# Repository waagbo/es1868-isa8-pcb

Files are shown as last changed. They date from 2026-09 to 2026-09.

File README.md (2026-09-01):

# ES1868F 8bit ISA Sound Card

## Introduction

This is a sound card for the ISA 8bit bus sporting the **ES1868F** chip by *ESS Technology*.

This chip provides **Sound Blaster PRO 2.0** (stereo), **OPL3** compatibility (via *ESFM*), MPU-401 support and is considered one of the [best chips](https://www.philscomputerlab.com/ess-audiodrive-es1868.html) used in clone cards.

Rev. 1.1 Board

This board provides the following connections:

* Speaker out (amplified)
* Line out
* Line in
* AUX in (internal header, since rev 1.2)
* Microphone in (internal header)
* Joystick port
* MIDI on Joystick port
* Wavetable header
* Volume control header

### Disclaimer

I take NO responsibility for what happens if you decide to build and use this card. Your computer might crash, catch fire or be destroyed in other nasty ways.
You're encourauged to take what you deem fit from this, and use it in your projects!

### Functionalities

✅ means I tested the functionality and it works, ❌ means I tested the functionality and found issues, ? means that the functionality has yet to be tested.

* [✅] FM Synthesis via OPL3 clone (**ESFM**)
* [✅] Digital audio playback
* [✅] Stereo (left/right channel) check (Tested with Sound Blaster PRO Test program, digitized sound mode)
* [✅] Joystick port
* [✅] Speaker Out (amplified)
* [✅] Line out
* [✅] Line in
* [✅] AUX In
* [?] Microphone in
* [✅] MIDI output via Joystick port (tested using DOSMID MPU mode on a Roland SC55)
* [✅] Wavetable daughterboard

The card was tested on:

* [✅] 286 16Mhz / DOS 6.22
* [✅] NEC V20 9.54Mhz / DOS 6.22 (Use **UNISOUND**, see **Configuration** section below)
* [✅] NEC V20 4.77Mhz / DOS 6.22 (Use **UNISOUND**, see **Configuration** section below)
* [✅] 8088 8Mhz / DOS 6.22 (Use **UNISOUND**, see **Configuration** section below)
* [✅] 8088 4.77Mhz / DOS 6.22 (Use **UNISOUND**, see **Configuration** section below)
* [✅] 486DX 40Mhz / DOS 7.1 (Use **UNISOUND**, see **Configuration** section below)
* [✅] Am5x86 40/160Mhz / DOS 7.1 (Use **UNISOUND**, see **Configuration** section below)

## Configuration

This card is jumperless and must be configured before use.
Under DOS you can us the [ESSCFG](software/ESSCFG.EXE) tool and tweak the volume via [ESSVOL](software/ESSVOL.EXE).

The **recommended** way to do this (especially under a very slow machine, like a V20/8088) is by using the [UNISOUND](https://www.vogons.org/viewtopic.php?f=62&t=72553) configurator.

It's important to add the `/XEA` parameter to `UNISOUND.COM` when using it, and remember to execute it after setting the `BLASTER` environment variable, for example with the command `SET BLASTER=A220 I5 D1 P330 T5 J201` (clearly changing the parameters depending on your setup).

**WARNING**: If you use an XT-IDE adapter at the default base address (300h), remember to set the MPU-401 base for this card to something else (like 330h)!

## Bill of Materials

See [BOM_smd.md](BOM_smd.md) / [BOM_smd.csv](BOM_smd.csv) for the SMD variant of the board
(`ISA_ES1868_smd.*`, see [SMD_CONVERSION.md](SMD_CONVERSION.md)), with DigiKey, Mouser and
LCSC part numbers.

Value of L1/L2/L3 ferrite beads is non critical. On the original THT board I used [these](https://www.mouser.it/ProductDetail/623-2743001112LF); the SMD variant uses the same 0805 bead as L4–L9/L12.

## Known Issues

### Rev 1.0

* Joystick plug "J3" silkscreen overlaps with some resistors (fixed in 1.1).
* The thread in the audio jacks I'm using (Kycon STX-3100-3CB) is flush with the bracket, so if the bracket has some bending, the plug risks to be pushed away (fixed in 1.1 by moving the connectors 0,5mm towards the edge).

## Credits

Thanks to [Sergey Kiselev](https://github.com/skiselev) for his symbol/footprint library!

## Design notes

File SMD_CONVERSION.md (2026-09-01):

# SMD Conversion Notes (`ISA_ES1868_smd`)

`ISA_ES1868_smd.kicad_pcb` / `.kicad_sch` / `.kicad_pro` are a copy of the rev 1.2 project
with through-hole parts converted to hand-solderable SMD footprints. The files are saved in
KiCad 10 format (the original rev 1.2 files are untouched and remain KiCad 7).

## What was converted

| Group | Old footprint | New footprint | Refs |
|---|---|---|---|
| Ceramic disc capacitors (38) | `C_Disc_D6.0mm` / `D3.8mm` | `C_0805_..._HandSolder` | C1–C11, C15–C33, C38–C41, C46–C48, C53 |
| 10 µF electrolytics on supply/bias nets (5) | `CP_Radial_D5.0mm` | `C_0805_..._HandSolder` (MLCC) | C12, C13, C50, C51, C52 |
| Resistors (34) | `R_Axial_DIN0207` | `R_0805_..._HandSolder` | R1–R18, R22–R37 |
| Axial ferrite beads (3) | `L_Axial_Vishay_IM-1` | `L_0805_..._HandSolder` | L1, L2, L3 (now same bead as L4–L9/L12) |
| 78L05 regulator | TO-92 | `SOT-89-3_Handsoldering` | U1 (pin functions 1=OUT/2=GND/3=IN identical in both packages) |
| 74LS138 decoder | DIP-16 | `SOIC-16_3.9x9.9mm` | U2 |
| 93LC66 EEPROM | DIP-8 | `SOIC-8_3.9x4.9mm` | U4 |

All converted parts keep their original position, rotation, reference, value and pad-net
assignments (verified pad-by-pad against the original board — zero net differences).

Like the original board, the converted parts print their **value on the front silkscreen**
(1×1 mm text, 0.15 mm stroke — same style as the THT originals). Ferrite beads keep their
values hidden, matching the original convention for L4–L12. Expect to nudge some value labels
apart while re-routing dense areas.

## What deliberately stays through-hole

* **U3 ES1868F** — already SMD (LQFP).
* **U7 LM1877 (DIP-14)** — no SMD package of this part ever existed; the chip itself is obsolete
  (see BOM notes).
* **Audio-path electrolytics** — kept as THT radial on purpose:
  * C36, C37 (10 µF): line-out coupling caps. A ceramic here would add DC-bias/piezo distortion;
    a leaded electrolytic (or audio-grade type) is the better part, and THT radials are trivial
    to hand solder.
  * C34, C35 (470 µF): speaker output coupling after the LM1877.
  * C14, C43 (47 µF): ES1868 VREF/CMR filter and LM1877 bias bypass — value too large for a
    sane 0805 ceramic, and both sit in audio-relevant reference nodes.
  * C42 (100 µF): amplifier supply bulk on `/Filtered_12V`.
* **Y1 crystal, all connectors, ISA edge, solder jumpers** — unchanged.

## Audio-circuit classification of the capacitors

Positions that are **in the audio signal path** (choose good dielectrics here):

| Refs | Function | Recommendation |
|---|---|---|
| C27, C28 (220 nF) | Line-in coupling | 50 V X7R 0805 (voltage headroom minimises C(V) distortion) |
| C31, C32 (220 nF) | AUX A coupling | 50 V X7R 0805 |
| C29, C30 (220 nF) | AUX B (wavetable) coupling | 50 V X7R 0805 |
| C8, C9 (220 nF) | FM out → codec in coupling | 50 V X7R 0805 |
| C47, C48 (220 nF) | LM1877 input coupling | 50 V X7R 0805 |
| C6 (100 nF) | Mic coupling | 50 V X7R 0805 |
| C10, C33 (1 nF) | Codec input filters | **C0G/NP0** |
| C38, C39 (10 nF) | LM1877 feedback | **C0G/NP0** |
| C40, C41 (100 nF) | LM1877 Zobel/snubber | 50 V X7R |
| C36, C37 (10 µF) | Line-out coupling | THT electrolytic (audio grade optional) |
| C34, C35 (470 µF) | Speaker coupling | THT electrolytic |

The original card used ceramic discs in all the small-value audio positions, so 0805 MLCCs are
not a downgrade — using 50 V-rated X7R (never Y5V/X5R for coupling) keeps distortion negligible
at ~1 Vrms line levels.

Non-audio positions: supply decoupling (C1–C5, C17, C50–C53, C12, C42), joystick timing caps
(C18–C21, C23–C26 — use **C0G** so gameport position readings stay stable with temperature),
crystal load caps (C15, C16 — **C0G**), reset filter (C46), VREF/bias filters (C7, C11, C13, C14,
C22, C43).

## Layout status — re-routing required

The converted footprints sit at the old component centroids, but 0805 pads do not land on the
old THT pad locations, so **the tracks around every converted part need to be re-routed** before
fabrication. DRC (`kicad-cli pcb drc --schematic-parity`) against the original board shows:

* schematic parity: **identical to the original** (the 188 reported net-name conflicts also
  exist on the untouched rev 1.2 board — they are KiCad 7 → 10 auto-net renaming, not errors),
* ~157 unconnected items + clearance/short/mask violations, all clustered at converted parts:
  this is exactly the pending re-route work. The old routing was left in place so it can be
  dragged/reused; the ratsnest shows every required connection.

Note: several THT pads were also used as layer-change points — where a track reached a
converted component on the back copper layer, a via is now needed.

## BOM

See [BOM_smd.csv](BOM_smd.csv) / [BOM_smd.md](BOM_smd.md) for the full bill of materials with
DigiKey, Mouser and LCSC alternatives.

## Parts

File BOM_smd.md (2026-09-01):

# Bill of Materials — ISA_ES1868_smd (SMD variant)

BOM for the SMD conversion of the rev 1.2 board (see [SMD_CONVERSION.md](SMD_CONVERSION.md)).
All SMD passives are 0805 with hand-solder footprints. Every DigiKey SKU below was verified on
DigiKey product pages on 2026-09-01 (stock changes — treat quantities as a snapshot). Mouser
cells say *search MPN* where the SKU couldn't be verified (Mouser blocks automated checks);
the MPN finds the part. Machine-readable version: [BOM_smd.csv](BOM_smd.csv).

**Audio path** marks parts where dielectric/type quality audibly matters — see notes at the bottom.

## SMD capacitors (0805)

| Qty | Refs | Value | Type | MPN | DigiKey | LCSC | Audio path |
|----:|---|---|---|---|---|---|---|
| 12 | C1–C7, C11, C17, C40, C41, C53 | 100 nF | X7R 50 V | KEMET C0805C104K5RACTU | 399-C0805C104K5RACTUCT-ND | C1711 (Samsung) | C6 (mic), C40/C41 (Zobel) |
| 10 | C8, C9, C27–C32, C47, C48 | 220 nF | X7R 50 V | KEMET C0805C224K5RACTU | 399-C0805C224K5RACTUCT-ND | C5378 (Samsung) | **yes — all coupling caps** |
| 10 | C18–C21, C23–C26, C38, C39 | 10 nF | **C0G** 50 V | KEMET C0805C103J5GACTU | 399-C0805C103J5GACTUCT-ND | C63849 (FH) | C38/C39 (amp feedback) |
| 3 | C10, C33, C46 | 1 nF | **C0G** 50 V | KEMET C0805C102J5GACTU | 399-C0805C102J5GACTUCT-ND | C1791 (Samsung) | C10/C33 (codec filters) |
| 1 | C22 | 150 pF | **C0G** 50 V | KEMET C0805C151J5GACTU | 399-C0805C151J5GACTUCT-ND | search `0805CG151J500NT` | no |
| 2 | C15, C16 | 10 pF | **C0G** 50 V | KEMET C0805C100J5GACTU | 399-C0805C100J5GAC7800CT-ND | C123640 (Walsin) | no — crystal load |
| 5 | C12, C13, C50–C52 | 10 µF | X5R 25 V | TDK C2012X5R1E106K085AC | 445-14387-1-ND | C15850 (Samsung CL21A106KAYNNNE) | no |

The Samsung CL21A106KAYNNNE (10 µF) was **0-stock at DigiKey** (restock ~2026-10-12) — the TDK
part is the verified in-stock equivalent there; at LCSC the Samsung is the pick (1.9 M pcs).

## Through-hole electrolytics (kept THT on purpose — audio path)

| Qty | Refs | Value | Size | Part (DigiKey pick) | DigiKey | LCSC | Role |
|----:|---|---|---|---|---|---|---|
| 2 | C36, C37 | 10 µF 50/63 V | ø5 · p2 | Rubycon **63PX10MEFC5X11** | 1189-1474-ND (4,999) | **C1579840 (Nichicon Muse FG UFG1H100MDM)** | line-out coupling |
| 2 | C14, C43 | 47 µF 25 V | ø5 · p2 | Rubycon **25PK47MEFC5X11** | 1189-25PK47MEFC5X11-ND (2,999) | C22320 (Chengx, 16 V) | VREF / amp bias |
| 1 | C42 | 100 µF 16 V | ø5 · p2 | Nichicon UVR1C101MDD1TA | 493-6095-1-ND (1,439 — EOL when depleted) | C2960196 (HRK) | amp supply bulk |
| 2 | C34, C35 | 470 µF 16 V | ø8 · p3.5 | Panasonic **ECA-1CM471** | P5141-ND | C43823 (Chengx) | speaker-out coupling |

The audio-grade Nichicons originally suggested here (Muse FG UFG1H100MDM, FW UFW1E470MDD) are
**obsolete at DigiKey** — the Rubycon PX/PK parts above are the verified in-stock same-size subs.
If you want the genuine Muse FG for C36/C37, LCSC still stocks it (C1579840), Mouser lists
647-UFG1H100MDM (stock unverified). Backup for C42: Panasonic ECA-1CM101 (12,750 pcs).

## Resistors (0805, thick film 1 %)

Yageo RC0805FR-07 series (all DigiKey SKUs verified in stock); UNI-ROYAL 0805W8F at LCSC.

| Qty | Refs | Value | Yageo MPN | DigiKey | LCSC |
|----:|---|---|---|---|---|
| 2 | R28, R29 | 2.7 Ω | RC0805FR-072R7L | 13-RC0805FR-072R7LCT-ND | C137450 (5 %, fine here) |
| 4 | R14–R17 | 1 kΩ | RC0805FR-071KL | 311-1.00KCRCT-ND | C17513 |
| 10 | R3–R6, R8–R13 | 2.2 kΩ | RC0805FR-072K2L | 311-2.20KCRCT-ND | C17520 |
| 2 | R1, R2 | 7.5 kΩ | RC0805FR-077K5L | 311-7.50KCRCT-ND | C17807 |
| 3 | R7, R32, R33 | 10 kΩ | RC0805FR-0710KL | 311-10.0KCRCT-ND | C17414 |
| 2 | R30, R31 | 15 kΩ | RC0805FR-0715KL | 311-15.0KCRCT-ND | C17475 |
| 1 | R18 | 22 kΩ | RC0805FR-0722KL | 311-22.0KCRCT-ND | C17560 |
| 2 | R22, R23 | 33 kΩ | RC0805FR-0733KL | 311-33.0KCRCT-ND | C17633 |
| 4 | R24–R27 | 820 kΩ | RC0805FR-07820KL | 311-820KCRCT-ND | C50136 (restocked, 23 k) |
| 4 | R34–R37 | 1 MΩ | RC0805FR-071ML | 311-1.00MCRCT-ND | C17514 |

LCSC 820 k alternates if C50136 dips again: C2771112 (UNI-ROYAL CQ), C7431038 (thin film 0.1 %).

## Ferrite beads (0805)

| Qty | Refs | Part | DigiKey | LCSC | Notes |
|----:|---|---|---|---|---|
| 10 | L1–L9, L12 | Murata **BLM21PG331SN1D** (330 Ω @ 100 MHz, 1.5 A) | 490-5988-1-ND | C74764 | Board previously said `BLM21PG331BH1D` — real Murata PN but not distributor-stocked; SN1D is the stocked equivalent. L1–L3 were axial beads, now identical to the rest. |
| 2 | L10, L11 | TDK **MPZ2012S601AT000** (600 Ω @ 100 MHz, **2 A**) | 445-MPZ2012S601AT000CT-ND (1.1 M) | C1017 (Sunlord GZ2012D601TF, 500 mA) | **Recommended replacement** for the original Würth 742792093 (2.2 kΩ but only 200 mA — marginal vs ~350 mA speaker peaks). Original Würth: 732-1609-1-ND if you want to match rev 1.2 exactly. |

## Semiconductors

| Ref | Part | Package | DigiKey | LCSC | Notes |
|---|---|---|---|---|---|
| U3 | **ES1868F** | LQFP-100 | — | — | NOS only — see alternatives below. |
| U1 | ST L78L05ABUTR | SOT-89 | 497-1181-1-ND | C42738 | Was TO-92; pin functions identical (1=OUT, 2=GND, 3=IN). |
| U2 | TI SN74LS138D | SOIC-16 | **296-3648-5-ND** (direct, 1,179) | C5965 (74HCT138D) | Avoid the Marketplace listing that ranks first in search. Cut tape: SN74LS138DR = 296-14883-1-ND (8,360). Nexperia 74HCT138D,653 is a drop-in modern alternative. |
| U4 | Microchip **93AA66C-I/SN** | SOIC-8 | **93AA66C-I/SN-ND** (3,283) | C153277 | **ORG pin is grounded on this board (×8 org)** → an ORG-selectable **C-variant is required**; never 93LC66A/B (fixed org). 93AA66C runs 1.8–5.5 V, fine at 5 V, deepest stock. Also works: 93LC66C-I/SN (93LC66C-I/SN-ND, 410) and DIP 93LC66C-I/P (93LC66C-I/P-ND, 340). |
| U7 | **LM1877N-9** | DIP-14 THT | obsolete | — | NOS still cheap — see alternatives below. Fit a DIP-14 socket. |
| Y1 | ECS **ECS-143-20-4X** 14.31818 MHz HC-49/US 20 pF | THT | **X1081-ND** (10,892, direct) | C2206 (YXC, 20 pF) | 18 pF option, also DigiKey-direct: Abracon ABLS-14.31818MHZ-B4-T = 535-10222-1-ND (772). The earlier B2-T suggestion was Marketplace-only. |

## Connectors & hardware

| Qty | Refs | Part | DigiKey | Mouser | LCSC | Notes |
|----:|---|---|---|---|---|---|
| 3 | J1, J2, J7 | Same Sky **SJ1-3553NG** 3.5 mm stereo, long bushing | CP1-3553NG-ND (**0 stock — restock ~2026-10-12**) | search MPN | — | Long bushing clears the bracket (per `docs/`). **In stock now:** SJ1-3523N = CP1-3523N-ND (233 k, short bushing), SJ1-3533N = CP1-3533N-ND (11 k, mid bushing), Kycon STX-3100-**3C** = 2092-STX-3100-3C-ND (1,883). LCSC PJ325 is 5-pin — not compatible. |
| 1 | J3 | DA-15 female right-angle (NorComp 182-015-213R531) | 182-15FE-ND | 152-3415 (Kobiconn) | C77835 (CONNFLY) | Check mounting holes vs. the 152-3415 drawing in `docs/`. |
| 1 | J5 | 2×13 header (Sullins PRPC013DAAN-RC) | 35-PRPC013DAAN-RC-ND (639) | search MPN | C2333 (cut 2×40) | Wavetable. |
| 1 | J10 | 2×3 header (PRPC003DAAN-RC) | 35-PRPC003DAAN-RC-ND (2,857) | search MPN | C65114 | Volume buttons. |
| 1 | J9 | 1×3 header (PRPC003SAAN-RC) | 35-PRPC003SAAN-RC-ND (455) | search MPN | C49257 | AUX in (carries audio). |
| 1 | J8 | 1×2 right-angle: snap 2 pins off Sullins PRPC040SBAN-M71RC | S1111EC-40-ND (5,912) | search MPN | C2334 (RA strip) | Dedicated 1×2 RA part is 0-stock at DigiKey. Mic in (carries audio). |
| 1 | — | Keystone **9200-3** ISA bracket | 36-9200-3-ND | search 9200-3 | — | Only the DA-15 cutout is punched — jack holes need drilling or a custom bracket. `docs/` also references Keystone 9204-1. |
| 1 | — | DIP-14 socket for U7 | generic | generic | generic | Strongly recommended — LM1877 scarcity. |

JP1–JP8 are solder jumpers and J11 is the ISA edge — part of the PCB, nothing to buy.

## Obsolete & hard-to-get parts — investigated alternatives

### U7 — LM1877N-9 (dual 2 W amp, obsolete since ~2008)

NOS supply is still healthy and cheap (checked 2026-09-01):

| Source | Status | Price | Confidence |
|---|---|---|---|
| Quest Components | 18 pcs in stock | $14.06 (qty 1) / $9.37 (8+) | verified count, NSC-branded — most credible |
| Jameco #23288 | listed | $3.35 | reputable seller, "Major Brands" house label |
| UTsource | in stock | $2.18 | gray-market broker, authenticity unverified |
| eBay | many singles | ~$3–8 | US/UK surplus singles look genuine; avoid 50-pc CN lots |
| Rochester Electronics | **no listing** | — | — |

Pin-compatible siblings LM377/LM378 are verified pin-identical but equally obsolete and
broker-only — no advantage over buying LM1877 itself.

**If redesigning the amp section** (the speaker jack is ground-referenced, so any replacement
must produce single-ended outputs — BTL/class-D parts are out):

* **Best: 2× TI LM386N-4** (DIP-8, ~$1, active production, DigiKey/Mouser). Rated 5–18 V —
  the only active option comfortably above the 12 V rail — and its default gain (26 dB with
  pins 1/8 open) is exactly what the LM1877 network is set to, so no gain parts are needed.
  ~0.5–0.8 W/ch at 12 V vs the LM1877's 1.3 W — plenty for the use case. Two DIP-8s occupy
  roughly the DIP-14's area.
* **Budget one-chip: UTC TDA2822** (DIP-8, LCSC C73295, $0.09; SOP-8 C73296; HGSEMI TDA2822N
  C20613256). Caveats: 12 V is the *operating maximum* (15 V abs max) on the very rail this
  board provides, and gain is fixed at ~40 dB so the input needs attenuation. Buy UTC/HGSEMI
  branded from LCSC — "ST TDA2822M" from marketplaces is a common counterfeit that dies at 12 V.
* Ruled out: NJM2073D (obsolete at DigiKey/Mouser, weak), TEA2025 clones (12 V limit, DIP-16,
  ≥36 dB gain floor), HXJ8002 (mono), PAM/class-D (BTL-only).

### U3 — ES1868F

* Sourcing today: UTsource ~$16 ("in stock"), AliExpress single pcs and 5-pc lots (~$4–8
  typical, unverified), eBay mostly complete donor cards ($38–50). Buy a spare; broker
  authenticity is never guaranteed.
* **ES1869F is a workable fallback on this exact PCB** — verified by diffing the pin tables of
  `docs/ES1868-ESS.pdf` against `docs/es1869techmanual.pdf`: the PQFP-100 pinout is identical
  except four pins. On this board: pin 60 is tied to GND, which on the ES1869 selects
  MODE=0 = ES1868-compatible pin functions ✔; pin 42's C11 (100 nF to GND) suits both ✔;
  **pin 25 becomes MONO_OUT — JP1 must be left OPEN** (never strap it to VCC/GND) ⚠;
  pin 26 (VDDD on the '68) becomes MONO_IN and sits at 5 V — ugly but muted-by-default, and
  community swap reports (VOGONS) confirm working cards ⚠. With this board's ES1868 EEPROM
  data, Windows needs the ES1868 drivers (ES1869 drivers refuse to load); DOS is unaffected.
* ES688F is **not** a drop-in (earlier generation, no ESFM/PnP, needs companion chips).

### Other risk items

* **U4 EEPROM**: 93AA66C-I/SN has the deepest stock (3,283); onsemi CAT93C66VI-GT3 confirmed
  ORG-compatible but DigiKey-direct stock was 0 (Marketplace only) — skip unless restocked.
* **Y1 crystal**: both listed options are DigiKey-direct and in stock; the earlier
  ABLS-…-B2-T suggestion was Marketplace-only.
* **J1/J2/J7 jacks**: primary long-bushing part is backordered to Oct 2026 — the three
  in-stock alternatives above all fit the footprint (bushing length differs; check bracket fit).
* **820 kΩ at LCSC**: restocked (23 k pcs) with two verified alternates listed above.

## Audio-path capacitor notes

* The original card already used ceramic discs in every small-value audio position, so 0805
  MLCCs are not a downgrade. Use **50 V X7R** for the 100/220 nF coupling positions (voltage
  headroom keeps capacitance-vs-voltage distortion negligible at ~1 Vrms line level) and
  **C0G/NP0** everywhere ≤10 nF. Avoid X5R/Y5V in any audio position.
* The electrolytics that sit **in series with audio** (C36/C37 line out, C34/C35 speaker out)
  stayed through-hole so standard or audio-grade radials can be used — SMD ceramics of these
  values would distort, and THT radials are the easiest parts on the board to solder anyway.
* The five 10 µF that were converted to MLCC (C12, C13, C50–C52) are purely supply/bias
  filters — no audio signal crosses them.

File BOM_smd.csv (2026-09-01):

Item | Qty | References | Value | Package | Description | Audio path | Manufacturer | MPN | DigiKey | Mouser | LCSC | Notes
1 | 12 | C1,C2,C3,C4,C5,C6,C7,C11,C17,C40,C41,C53 | 100nF | 0805 | MLCC X7R 50V | C6/C40/C41 yes, rest decoupling/bias | KEMET | C0805C104K5RACTU | 399-C0805C104K5RACTUCT-ND | search MPN | C1711 (Samsung CL21B104KBCNNNC) | 50V rating kept for the audio positions
2 | 10 | C8,C9,C27,C28,C29,C30,C31,C32,C47,C48 | 220nF | 0805 | MLCC X7R 50V | yes — input/output coupling | KEMET | C0805C224K5RACTU | 399-C0805C224K5RACTUCT-ND | search MPN | C5378 (Samsung CL21B224KBFNNNE) | Audio coupling: use 50V X7R; never Y5V/X5R here
3 | 10 | C18,C19,C20,C21,C23,C24,C25,C26,C38,C39 | 10nF | 0805 | MLCC C0G/NP0 50V | C38/C39 yes (amp feedback), rest joystick timing | KEMET | C0805C103J5GACTU | 399-C0805C103J5GACTUCT-ND | search MPN | C63849 (FH 0805CG103J500NT) | C0G for joystick timing stability and amp feedback linearity
4 | 3 | C10,C33,C46 | 1nF | 0805 | MLCC C0G/NP0 50V | C10/C33 yes (codec input filters) | KEMET | C0805C102J5GACTU | 399-C0805C102J5GACTUCT-ND | search MPN | C1791 (Samsung CL21C102JBCNNNC)
5 | 1 | C22 | 150pF | 0805 | MLCC C0G/NP0 50V | no — VCC filter | KEMET | C0805C151J5GACTU | 399-C0805C151J5GACTUCT-ND | search MPN | search 0805CG151J500NT (FH) | Not Google-indexed at LCSC; search on site
6 | 2 | C15,C16 | 10pF | 0805 | MLCC C0G/NP0 50V | no — crystal load | KEMET | C0805C100J5GACTU | 399-C0805C100J5GAC7800CT-ND | search MPN | C123640 (Walsin 0805N100J500CT)
7 | 5 | C12,C13,C50,C51,C52 | 10uF | 0805 | MLCC X5R 25V | no — supply bulk / mic-bias filter | TDK | C2012X5R1E106K085AC | 445-14387-1-ND | search MPN | C15850 (Samsung CL21A106KAYNNNE) | Samsung CL21A106KAYNNNE was 0-stock at DigiKey (restock ~2026-10) but is the LCSC pick; TDK part is the in-stock DigiKey equivalent
8 | 2 | C36,C37 | 10uF | radial 5mm p2, THT | Aluminum electrolytic 50/63V | yes — line-out coupling | Rubycon | 63PX10MEFC5X11 | 1189-1474-ND | 647-UFG1H100MDM (Nichicon FG) | C1579840 (Nichicon UFG1H100MDM) | Kept THT (audio path). Nichicon Muse FG UFG1H100MDM is obsolete at DigiKey but still at LCSC/Mouser; Rubycon PX is the in-stock DigiKey sub (5x11mm 2mm pitch)
9 | 2 | C14,C43 | 47uF | radial 5mm p2, THT | Aluminum electrolytic 25V | partly — VREF/bias filters | Rubycon | 25PK47MEFC5X11 | 1189-25PK47MEFC5X11-ND | search UFW1E470MDD | C22320 (Chengx 16V) | Nichicon FW UFW1E470MDD is obsolete at DigiKey; Rubycon PK is the in-stock sub (5x11mm 2mm pitch)
10 | 1 | C42 | 100uF | radial 5mm p2, THT | Aluminum electrolytic 16V | no — amp supply bulk | Nichicon | UVR1C101MDD1TA | 493-6095-1-ND | search MPN | C2960196 (HRK CD110 16V) | 1439 left / obsolete-once-depleted at DigiKey; backup Panasonic ECA-1CM101 (12750 in stock)
11 | 2 | C34,C35 | 470uF | radial 8mm p3.5, THT | Aluminum electrolytic 16V | yes — speaker-out coupling | Panasonic | ECA-1CM471 | P5141-ND | search MPN | C43823 (Chengx GR477M016F12RR0VL4FP0) | 8x11.5mm 3.5mm pitch confirmed
12 | 10 | L1,L2,L3,L4,L5,L6,L7,L8,L9,L12 | BLM21PG331SN1D | 0805 | Ferrite bead 330R@100MHz 1.5A | bead in audio/supply filtering | Murata | BLM21PG331SN1D | 490-5988-1-ND | stocked (search MPN) | C74764 | Board previously said BH1D (real Murata PN but not distributor-stocked); SN1D is the same 330R spec and stocked. L1-L3 were axial Fair-Rite beads, now same 0805 bead
13 | 2 | L10,L11 | MPZ2012S601AT000 | 0805 | Ferrite bead 600R@100MHz 2A | yes — speaker output lines | TDK | MPZ2012S601AT000 | 445-MPZ2012S601AT000CT-ND | search MPN | C1017 (Sunlord GZ2012D601TF 500mA) | RECOMMENDED over the original Wurth 742792093 (2.2k@100MHz but only 200mA - marginal vs ~350mA speaker peaks). Original Wurth: DigiKey 732-1609-1-ND if you want to match rev 1.2 exactly
14 | 2 | R28,R29 | 2.7R | 0805 | Thick film 1% | yes — amp Zobel/snubber | Yageo | RC0805FR-072R7L | 13-RC0805FR-072R7LCT-ND | search MPN | C137450 (RC0805JR-072R7L 5%) | 5% fine in this position
15 | 4 | R14,R15,R16,R17 | 1k | 0805 | Thick film 1% | no | Yageo | RC0805FR-071KL | 311-1.00KCRCT-ND | search MPN | C17513 (UNI-ROYAL 0805W8F1001T5E)
16 | 10 | R3,R4,R5,R6,R8,R9,R10,R11,R12,R13 | 2.2k | 0805 | Thick film 1% | no — joystick/MIDI | Yageo | RC0805FR-072K2L | 311-2.20KCRCT-ND | search MPN | C17520 (UNI-ROYAL 0805W8F2201T5E)
17 | 2 | R1,R2 | 7.5k | 0805 | Thick film 1% | no — mic bias | Yageo | RC0805FR-077K5L | 311-7.50KCRCT-ND | search MPN | C17807 (UNI-ROYAL 0805W8F7501T5E)
18 | 3 | R7,R32,R33 | 10k | 0805 | Thick film 1% | R32/R33 yes (amp input bias) | Yageo | RC0805FR-0710KL | 311-10.0KCRCT-ND | search MPN | C17414 (UNI-ROYAL 0805W8F1002T5E)
19 | 2 | R30,R31 | 15k | 0805 | Thick film 1% | yes — amp input series | Yageo | RC0805FR-0715KL | 311-15.0KCRCT-ND | search MPN | C17475 (UNI-ROYAL 0805W8F1502T5E)
20 | 1 | R18 | 22k | 0805 | Thick film 1% | no — MCLK pulldown | Yageo | RC0805FR-0722KL | 311-22.0KCRCT-ND | search MPN | C17560 (UNI-ROYAL 0805W8F2202T5E)
21 | 2 | R22,R23 | 33k | 0805 | Thick film 1% | yes — amp gain set | Yageo | RC0805FR-0733KL | 311-33.0KCRCT-ND | search MPN | C17633 (UNI-ROYAL 0805W8F3302T5E)
22 | 4 | R24,R25,R26,R27 | 820k | 0805 | Thick film 1% | yes — amp feedback | Yageo | RC0805FR-07820KL | 311-820KCRCT-ND | search MPN | C50136 (UNI-ROYAL; restocked 23k pcs) | LCSC alternates: C2771112, C7431038 (thin film 0.1%)
23 | 4 | R34,R35,R36,R37 | 1M | 0805 | Thick film 1% | no — joystick bleed | Yageo | RC0805FR-071ML | 311-1.00MCRCT-ND | search MPN | C17514 (UNI-ROYAL 0805W8F1004T5E)
24 | 1 | U1 | L78L05 | SOT-89 | 5V 100mA linear regulator | no | STMicroelectronics | L78L05ABUTR | 497-1181-1-ND | stocked (search MPN) | C42738 | Converted from TO-92; pin functions identical (1=OUT 2=GND 3=IN)
25 | 1 | U2 | 74LS138 | SOIC-16 | 3-to-8 line decoder | no | Texas Instruments | SN74LS138D | 296-3648-5-ND (direct; avoid Marketplace listing) | search MPN | C5965 (Nexperia 74HCT138D. 653) | Cut tape SN74LS138DR = 296-14883-1-ND. 74HCT138D is a drop-in modern alternative; LCSC only stocks the HCT
26 | 1 | U4 | 93LC66 | SOIC-8 | 4kbit Microwire EEPROM | no | Microchip | 93AA66C-I/SN | 93AA66C-I/SN-ND (3283 pcs) | search MPN | C153277 (93AA66C-I/SN) | ORG pin is tied to GND on this board (x8 org) so an ORG-selectable C-variant is REQUIRED - never 93LC66A/B (fixed org). 93AA66C works fine at 5V and has the deepest stock; 93LC66C-I/SN (93LC66C-I/SN-ND, 410 pcs) and DIP 93LC66C-I/P (340 pcs) also work
27 | 1 | U3 | ES1868F | LQFP-100 | ESS AudioDrive sound chip | yes | ESS Technology | ES1868F | not stocked | not stocked | not stocked | NOS only: UTsource ~$16 / AliExpress ~$4-8 / donor card ($38-50 on eBay). Buy a spare - broker authenticity unverified. FALLBACK: ES1869F fits this PCB (verified pin diff; leave JP1 OPEN - pin 25 becomes MONO_OUT; pin 26 gets 5V on muted MONO_IN - community-tolerated; use ES1868 drivers under Windows). See BOM_smd.md
28 | 1 | U7 | LM1877 | DIP-14 (THT) | Dual 2W audio power amplifier | yes | National/TI | LM1877N-9 | OBSOLETE - not stocked | OBSOLETE - not stocked | not stocked | NOS still cheap and findable: Quest Components (18 pcs @ $14 - verified NSC stock) / Jameco #23288 $3.35 (house brand) / UTsource $2.18 / eBay singles. Rochester has none. Fit a DIP-14 socket. Redesign option: 2x TI LM386N-4 (active - see BOM_smd.md)
29 | 1 | Y1 | 14.31818MHz | HC-49/US THT | Crystal, 18-20pF load | no | ECS | ECS-143-20-4X | X1081-ND (10892 pcs) | search MPN | C2206 (YXC X49SD1431818MSD2SC 20pF) | First-party in-stock pick (20pF). 18pF alternative: Abracon ABLS-14.31818MHZ-B4-T = 535-10222-1-ND (772 pcs, direct). Footprint is horizontal-mount with case-ground pad
30 | 3 | J1,J2,J7 | LINE IN / LINE OUT / SPKR OUT | 3.5mm TRS jack THT | Stereo audio jack, 3-pin | yes | Same Sky (CUI) | SJ1-3553NG | CP1-3553NG-ND (0 stock; restock ~2026-10-12) | search MPN | no compatible part | Long-bushing version per author's docs (clears bracket). IN-STOCK alternatives: SJ1-3523N = CP1-3523N-ND (233k pcs) short bushing; SJ1-3533N = CP1-3533N-ND (11k pcs); Kycon STX-3100-3C = 2092-STX-3100-3C-ND (1883 pcs). LCSC PJ325 is 5-pin and NOT footprint-compatible
31 | 1 | J3 | Joystick/MIDI | DA-15 female right-angle THT | Gameport D-sub | no | NorComp | 182-015-213R531 | 182-15FE-ND | 152-3415 (Kobiconn) | C77835 (CONNFLY DS1037-15FNAKT74-0CC) | Verify mounting-hole pattern against the 152-3415 drawing in docs/
32 | 1 | J5 | Wavetable | 2x13 pin header 2.54mm | Wavetable daughterboard header | no | Sullins | PRPC013DAAN-RC | 35-PRPC013DAAN-RC-ND | search MPN | C2333 (cut 2x40 breakaway)
33 | 1 | J10 | Vol. Btns | 2x3 pin header 2.54mm | Volume buttons header | no | Sullins | PRPC003DAAN-RC | 35-PRPC003DAAN-RC-ND | search MPN | C65114 (BOOMELE THT)
34 | 1 | J9 | AUX_A | 1x3 pin header 2.54mm | Aux in header | yes — carries audio | Sullins | PRPC003SAAN-RC | 35-PRPC003SAAN-RC-ND | search MPN | C49257 (BOOMELE)
35 | 1 | J8 | MIC IN | 1x2 right-angle header 2.54mm | Microphone header | yes — carries audio | Sullins | PRPC040SBAN-M71RC (snap off 2 pins) | S1111EC-40-ND | search MPN | C2334 (BOOMELE 1x40 RA strip) | Dedicated 1x2 RA (PRPC002SBCN-M71RC) is 0-stock; break-away strip covers it
36 | 1 | bracket | ISA bracket | hardware | PC slot bracket with DA-15 cutout | no | Keystone | 9200-3 | 36-9200-3-ND | 534-9200-3 (search 9200-3) | not stocked | docs/ also references Keystone 9204-1. Bracket has only the DA-15 cutout - the 3.5mm jack holes must be drilled/punched or a custom bracket used
37 | 1 | (optional) U7 socket | DIP-14 socket | THT | IC socket for LM1877 | no | generic | DIP-14 socket | search | search | search | Recommended given LM1877 scarcity
38 | - | JP1-JP8, J11 | solder jumpers / ISA edge | PCB | part of the PCB - nothing to buy

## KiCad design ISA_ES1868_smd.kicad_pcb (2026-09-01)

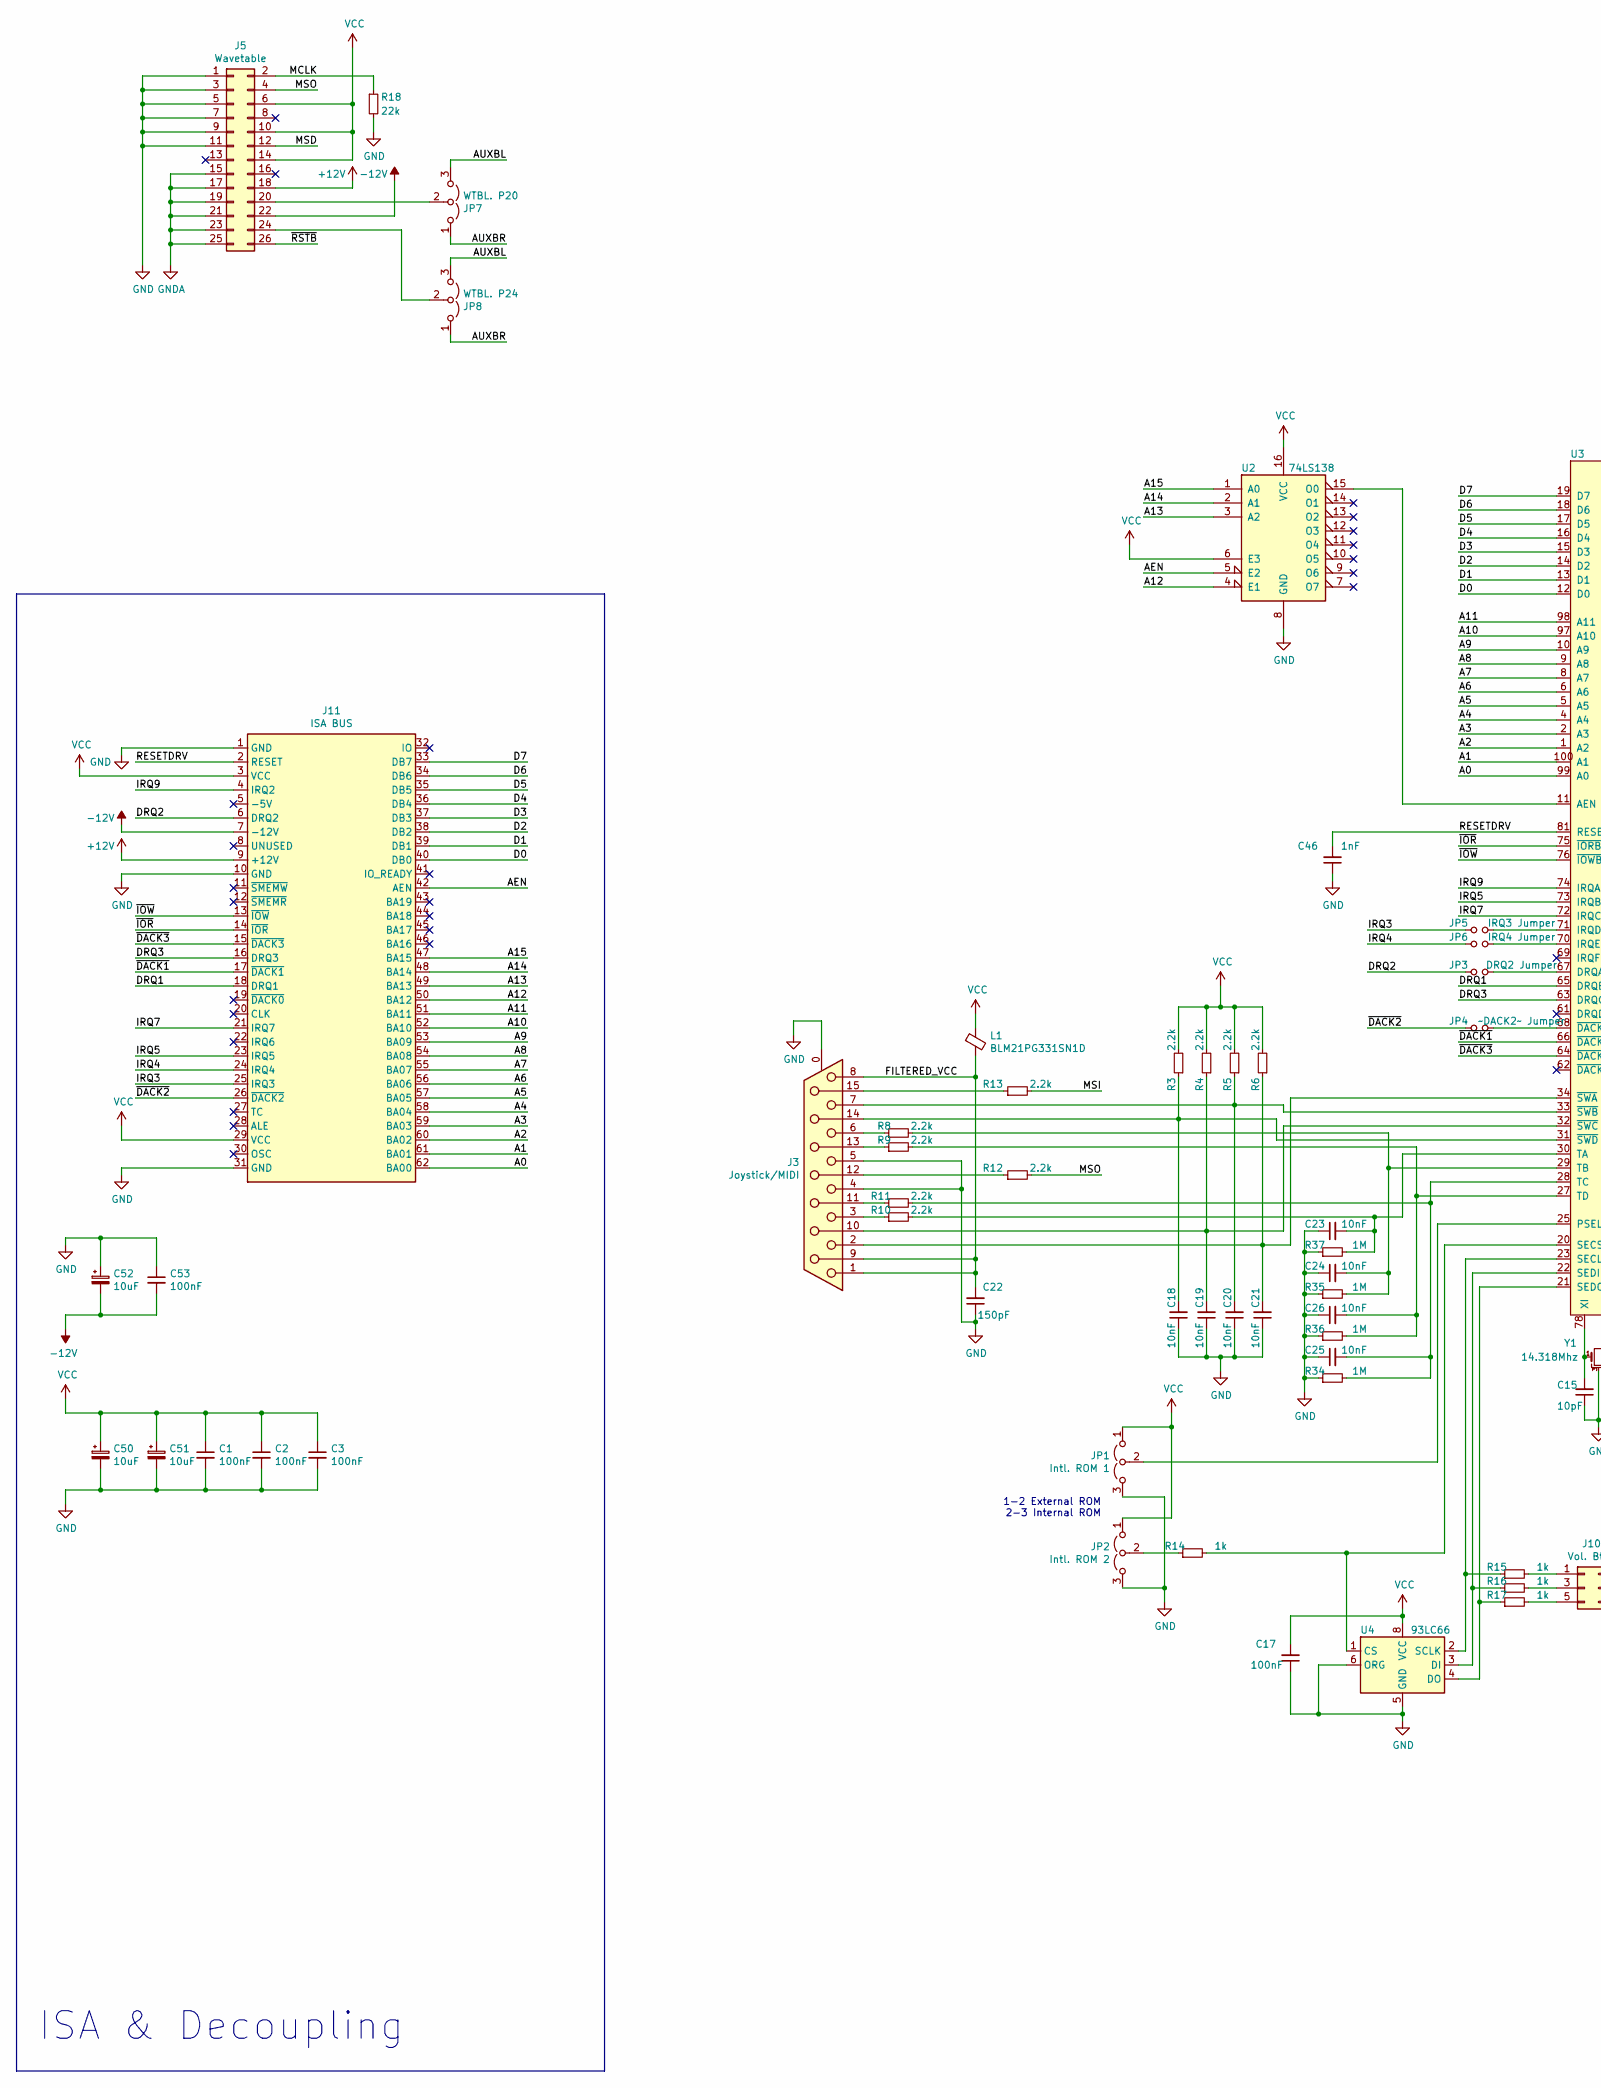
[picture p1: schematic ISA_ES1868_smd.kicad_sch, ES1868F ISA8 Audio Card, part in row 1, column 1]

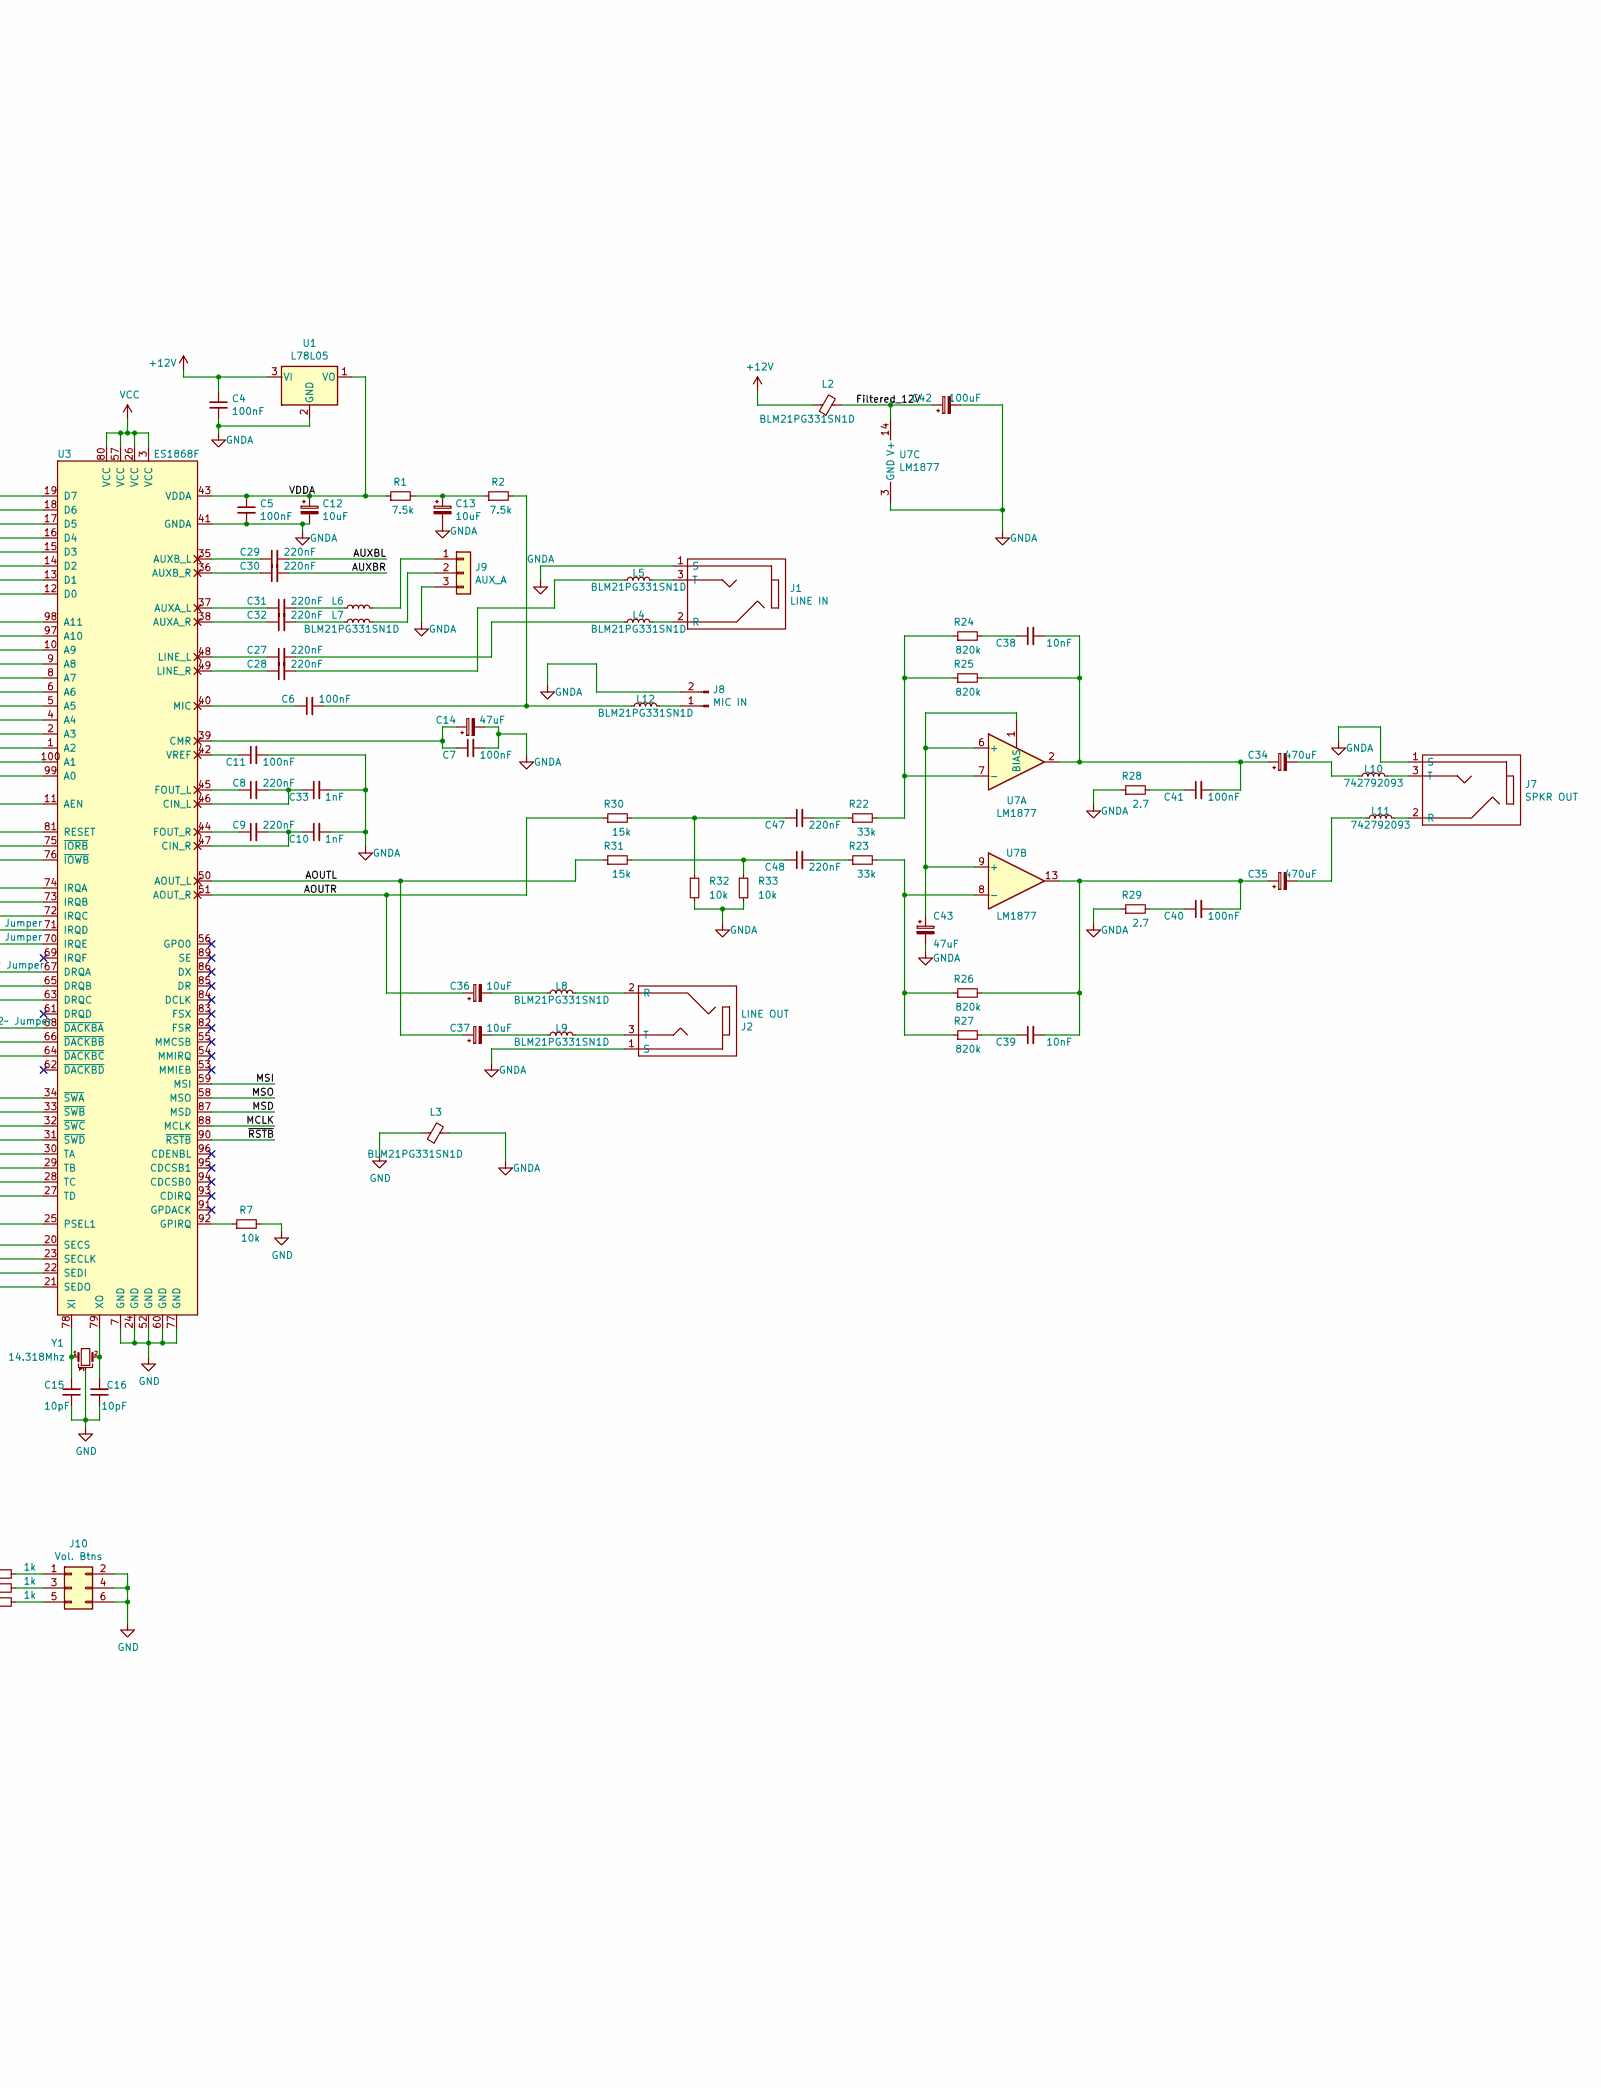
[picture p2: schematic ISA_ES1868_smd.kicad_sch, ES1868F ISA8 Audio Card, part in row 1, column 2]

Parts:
C1, C2, C3, C4, C5, C6, C7, C11, C17, C40, C41, C53: 100nF; C_0805_2012Metric_Pad1.18x1.45mm_HandSolder
C8, C9, C27, C28, C29, C30, C31, C32, C47, C48: 220nF; C_0805_2012Metric_Pad1.18x1.45mm_HandSolder
C10, C33, C46: 1nF; C_0805_2012Metric_Pad1.18x1.45mm_HandSolder
C12, C13, C50, C51, C52: 10uF; C_0805_2012Metric_Pad1.18x1.45mm_HandSolder
C14, C43: 47uF; CP_Radial_D5.0mm_P2.50mm
C15, C16: 10pF; C_0805_2012Metric_Pad1.18x1.45mm_HandSolder
C18, C19, C20, C21, C23, C24, C25, C26, C38, C39: 10nF; C_0805_2012Metric_Pad1.18x1.45mm_HandSolder
C22: 150pF; C_0805_2012Metric_Pad1.18x1.45mm_HandSolder
C34, C35: 470uF; CP_Radial_D8.0mm_P3.50mm
C36, C37: 10uF; CP_Radial_D5.0mm_P2.50mm
C42: 100uF; CP_Radial_D5.0mm_P2.50mm
J1: LINE IN; Conn_Audio_3.5mm_Stereo_SJ1-352XNG
J2: LINE OUT; Conn_Audio_3.5mm_Stereo_SJ1-352XNG
J3: Joystick/MIDI; SB_DB15_152-3415
J5: Wavetable; PinHeader_2x13_P2.54mm_Vertical
J7: SPKR OUT; Conn_Audio_3.5mm_Stereo_SJ1-352XNG
J8: MIC IN; PinHeader_1x02_P2.54mm_Horizontal
J9: AUX_A; PinHeader_1x03_P2.54mm_Vertical
J10: Vol. Btns; PinHeader_2x03_P2.54mm_Vertical
J11: ISA BUS; Conn_Edge_PCB_ISA8
JP1: Intl. ROM 1; SolderJumper-3_P1.3mm_Open_RoundedPad1.0x1.5mm_NumberLabels
JP2: Intl. ROM 2; SolderJumper-3_P1.3mm_Open_RoundedPad1.0x1.5mm_NumberLabels
JP3: DRQ2 Jumper; SolderJumper-2_P1.3mm_Open_RoundedPad1.0x1.5mm
JP4: ~DACK2~ Jumper; SolderJumper-2_P1.3mm_Open_RoundedPad1.0x1.5mm
JP5: IRQ3 Jumper; SolderJumper-2_P1.3mm_Open_RoundedPad1.0x1.5mm
JP6: IRQ4 Jumper; SolderJumper-2_P1.3mm_Open_RoundedPad1.0x1.5mm
JP7: WTBL. P20; SolderJumper-3_P1.3mm_Open_RoundedPad1.0x1.5mm_NumberLabels
JP8: WTBL. P24; SolderJumper-3_P1.3mm_Open_RoundedPad1.0x1.5mm_NumberLabels
L1, L2, L3, L4, L5, L6, L7, L8, L9, L12: BLM21PG331SN1D; L_0805_2012Metric_Pad1.15x1.40mm_HandSolder
L10, L11: 742792093; L_0805_2012Metric_Pad1.15x1.40mm_HandSolder
R1, R2: 7.5k; R_0805_2012Metric_Pad1.20x1.40mm_HandSolder
R3, R4, R5, R6, R8, R9, R10, R11, R12, R13: 2.2k; R_0805_2012Metric_Pad1.20x1.40mm_HandSolder
R7, R32, R33: 10k; R_0805_2012Metric_Pad1.20x1.40mm_HandSolder
R14, R15, R16, R17: 1k; R_0805_2012Metric_Pad1.20x1.40mm_HandSolder
R18: 22k; R_0805_2012Metric_Pad1.20x1.40mm_HandSolder
R22, R23: 33k; R_0805_2012Metric_Pad1.20x1.40mm_HandSolder
R24, R25, R26, R27: 820k; R_0805_2012Metric_Pad1.20x1.40mm_HandSolder
R28, R29: 2.7; R_0805_2012Metric_Pad1.20x1.40mm_HandSolder
R30, R31: 15k; R_0805_2012Metric_Pad1.20x1.40mm_HandSolder
R34, R35, R36, R37: 1M; R_0805_2012Metric_Pad1.20x1.40mm_HandSolder
U1: L78L05; SOT-89-3_Handsoldering
U2: 74LS138; SOIC-16_3.9x9.9mm_P1.27mm
U3: ES1868F; LQFP-14x20mm_P0.5mm
U4: 93LC66; SOIC-8_3.9x4.9mm_P1.27mm
U7: LM1877; DIP-14_W7.62mm_LongPads
Y1: 14.318Mhz; Crystal_HC49-U_Horizontal_1EP_style2

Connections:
+12V: C4.1, J5.18, J11.9 (+12V), L2.1, U1.3 (VI)
-12V: C52.2, C53.2, J5.22, J11.7 (-12V)
/A0: J11.62 (BA00), U3.99 (A0)
/A1: J11.61 (BA01), U3.100 (A1)
/A2: J11.60 (BA02), U3.1 (A2)
/A3: J11.59 (BA03), U3.2 (A3)
/A4: J11.58 (BA04), U3.4 (A4)
/A5: J11.57 (BA05), U3.5 (A5)
/A6: J11.56 (BA06), U3.6 (A6)
/A7: J11.55 (BA07), U3.8 (A7)
/A8: J11.54 (BA08), U3.9 (A8)
/A9: J11.53 (BA09), U3.10 (A9)
/A10: J11.52 (BA10), U3.97 (A10)
/A11: J11.51 (BA11), U3.98 (A11)
/A12: J11.50 (BA12), U2.4 (E1)
/A13: J11.49 (BA13), U2.3 (A2)
/A14: J11.48 (BA14), U2.2 (A1)
/A15: J11.47 (BA15), U2.1 (A0)
/AEN: J11.42 (AEN), U2.5 (E2)
/AOUTL: C37.1, R31.1, U3.50 (AOUT_L)
/AOUTR: C36.1, R30.1, U3.51 (AOUT_R)
/AUXBL: C29.2, JP7.3 (B), JP8.3 (B)
/AUXBR: C30.2, JP7.1 (A), JP8.1 (A)
/D0: J11.40 (DB0), U3.12 (D0)
/D1: J11.39 (DB1), U3.13 (D1)
/D2: J11.38 (DB2), U3.14 (D2)
/D3: J11.37 (DB3), U3.15 (D3)
/D4: J11.36 (DB4), U3.16 (D4)
/D5: J11.35 (DB5), U3.17 (D5)
/D6: J11.34 (DB6), U3.18 (D6)
/D7: J11.33 (DB7), U3.19 (D7)
/DRQ1: J11.18 (DRQ1), U3.65 (DRQB)
/DRQ2: J11.6 (DRQ2), JP3.1
/DRQ3: J11.16 (DRQ3), U3.63 (DRQC)
/FILTERED_VCC: C22.2, J3.1, J3.8, J3.9, L1.2
/Filtered_12V: C42.1, L2.2, U7.14 (V+)
/IRQ3: J11.25 (IRQ3), JP5.1
/IRQ4: J11.24 (IRQ4), JP6.1
/IRQ5: J11.23 (IRQ5), U3.73 (IRQB)
/IRQ7: J11.21 (IRQ7), U3.72 (IRQC)
/IRQ9: J11.4 (IRQ2), U3.74 (IRQA)
/MCLK: J5.2, R18.1, U3.88 (MCLK)
/MSD: J5.12, U3.87 (MSD)
/MSI: R13.2, U3.59 (MSI)
/MSO: J5.4, R12.2, U3.58 (MSO)
/RESETDRV: C46.2, J11.2 (RESET), U3.81 (RESET)
/VDDA: C5.1, C12.1, R1.1, U1.1 (VO), U3.43 (VDDA)
/~DACK1: J11.17 (~DACK1), U3.66 (~DACKBB)
/~DACK2: J11.26 (~DACK2), JP4.1
/~DACK3: J11.15 (~DACK3), U3.64 (~DACKBC)
/~IOR: J11.14 (~IOR), U3.75 (~IORB)
/~IOW: J11.13 (~IOW), U3.76 (~IOWB)
/~RSTB: J5.26, U3.90 (~RSTB)
GND: C1.2, C2.2, C3.2, C15.1, C16.1, C17.1, C18.1, C19.1, C20.1, C21.1, C22.1, C23.1, C24.1, C25.1, C26.1, C46.1, C50.2, C51.2, C52.1, C53.1, J3.0 (PAD), J3.4, J3.5, J5.1, J5.3, J5.5, J5.7, J5.9, J5.11, J10.2, J10.4, J10.6, J11.1 (GND), J11.10 (GND), J11.31 (GND), JP1.3 (B), JP2.3 (B), L3.1, R7.2, R18.2, R34.1, R35.1, R36.1, R37.1, U2.8 (GND), U3.7 (GND), U3.24 (GND), U3.52 (GND), U3.60 (GND), U3.77 (GND), U4.5 (GND), U4.6 (ORG), Y1.3
GNDA: C4.2, C5.2, C7.2, C10.2, C11.2, C12.2, C13.2, C14.2, C33.2, C42.2, C43.2, J1.1 (S), J2.1 (S), J5.15, J5.17, J5.19, J5.21, J5.23, J5.25, J7.1 (S), J8.2, J9.3, L3.2, R28.1, R29.1, R32.2, R33.2, U1.2 (GND), U3.41 (GNDA), U7.3 (GND), U7.4 (GND), U7.5 (GND), U7.10 (GND), U7.11 (GND), U7.12 (GND)
unnamed: C6.1, U3.40 (MIC)
unnamed: C6.2, L12.2, R2.2
unnamed: C8.1, U3.45 (FOUT_L)
unnamed: C9.1, U3.44 (FOUT_R)
unnamed: C9.2, C10.1, U3.47 (CIN_R)
unnamed: C11.1, U3.42 (VREF)
unnamed: C13.1, R1.2, R2.1
unnamed: C7.1, C14.1, U3.39 (CMR)
unnamed: C15.2, U3.78 (XI), Y1.1
unnamed: C16.2, U3.79 (XO), Y1.2
unnamed: C18.2, J3.14, R3.1, U3.31 (~SWD)
unnamed: C19.2, J3.10, R4.1, U3.32 (~SWC)
unnamed: C20.2, J3.7, R5.1, U3.33 (~SWB)
unnamed: C21.2, J3.2, R6.1, U3.34 (~SWA)
unnamed: C23.2, R10.2, R37.2, U3.30 (TA)
unnamed: C24.2, R8.2, R35.2, U3.29 (TB)
unnamed: C25.2, R11.2, R34.2, U3.28 (TC)
unnamed: C26.2, R9.2, R36.2, U3.27 (TD)
unnamed: C27.1, U3.48 (LINE_L)
unnamed: C27.2, L4.2
unnamed: C28.1, U3.49 (LINE_R)
unnamed: C28.2, L5.2
unnamed: C29.1, U3.35 (AUXB_L)
unnamed: C30.1, U3.36 (AUXB_R)
unnamed: C31.1, U3.37 (AUXA_L)
unnamed: C31.2, L6.2
unnamed: C32.1, U3.38 (AUXA_R)
unnamed: C32.2, L7.2
unnamed: C8.2, C33.1, U3.46 (CIN_L)
unnamed: C34.1, C38.2, C41.2, R25.2, U7.2
unnamed: C34.2, L10.2
unnamed: C35.1, C39.2, C40.2, R26.2, U7.13
unnamed: C35.2, L11.2
unnamed: C36.2, L8.2
unnamed: C37.2, L9.2
unnamed: C38.1, R24.2
unnamed: C39.1, R27.2
unnamed: C40.1, R29.2
unnamed: C41.1, R28.2
unnamed: C43.1, U7.1 (BIAS), U7.6 (+), U7.9 (+)
unnamed: C47.1, R30.2, R32.1
unnamed: C47.2, R22.1
unnamed: C48.1, R31.2, R33.1
unnamed: C48.2, R23.1
unnamed: J1.2 (R), L4.1
unnamed: J1.3 (T), L5.1
unnamed: J2.2 (R), L8.1
unnamed: J2.3 (T), L9.1
unnamed: J3.3, R10.1
unnamed: J3.6, R8.1
unnamed: J3.11 (P111), R11.1
unnamed: J3.12, R12.1
unnamed: J3.13, R9.1
unnamed: J3.15, R13.1
unnamed: J5.20, JP7.2 (C)
unnamed: J5.24, JP8.2 (C)
unnamed: J7.2 (R), L11.1
unnamed: J7.3 (T), L10.1
unnamed: J8.1, L12.1
unnamed: J9.1, L6.1
unnamed: J9.2, L7.1
unnamed: J10.1, R15.2
unnamed: J10.3, R16.2
unnamed: J10.5, R17.2
unnamed: JP1.2 (C), U3.25 (PSEL1)
unnamed: JP2.2 (C), R14.1
unnamed: JP3.2, U3.67 (DRQA)
unnamed: JP4.2, U3.68 (~DACKBA)
unnamed: JP5.2, U3.71 (IRQD)
unnamed: JP6.2, U3.70 (IRQE)
unnamed: R7.1, U3.92 (GPIRQ)
unnamed: R14.2, U3.20 (SECS), U4.1 (CS)
unnamed: R15.1, U3.23 (SECLK), U4.2 (SCLK)
unnamed: R16.1, U3.22 (SEDI), U4.3 (DI)
unnamed: R17.1, U3.21 (SEDO), U4.4 (DO)
unnamed: R22.2, R24.1, R25.1, U7.7 (-)
unnamed: R23.2, R26.1, R27.1, U7.8 (-)
unnamed: U2.15 (O0), U3.11 (AEN)
VCC: C1.1, C2.1, C3.1, C17.2, C50.1, C51.1, J5.6, J5.10, J5.14, J11.3 (VCC), J11.29 (VCC), JP1.1 (A), JP2.1 (A), L1.1, R3.2, R4.2, R5.2, R6.2, U2.6 (E3), U2.16 (VCC), U3.3 (VCC), U3.26 (VCC), U3.57 (VCC), U3.80 (VCC), U4.8 (VCC)

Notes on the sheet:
ISA & Decoupling
1-2 External ROM 2-3 Internal ROM

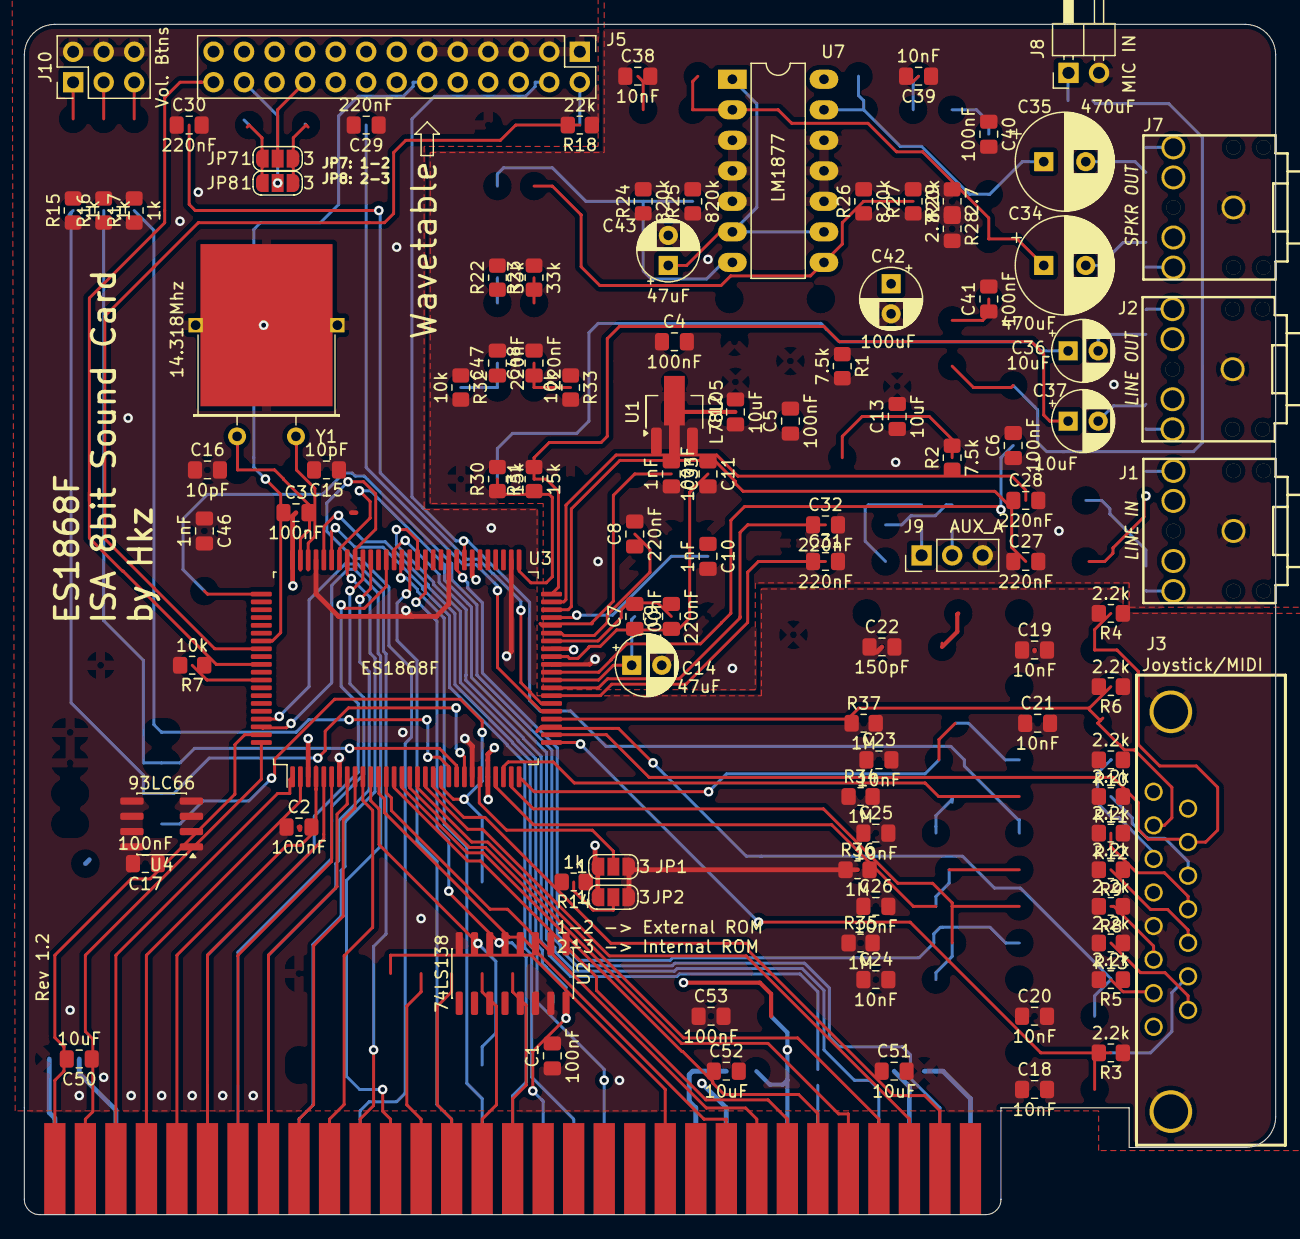
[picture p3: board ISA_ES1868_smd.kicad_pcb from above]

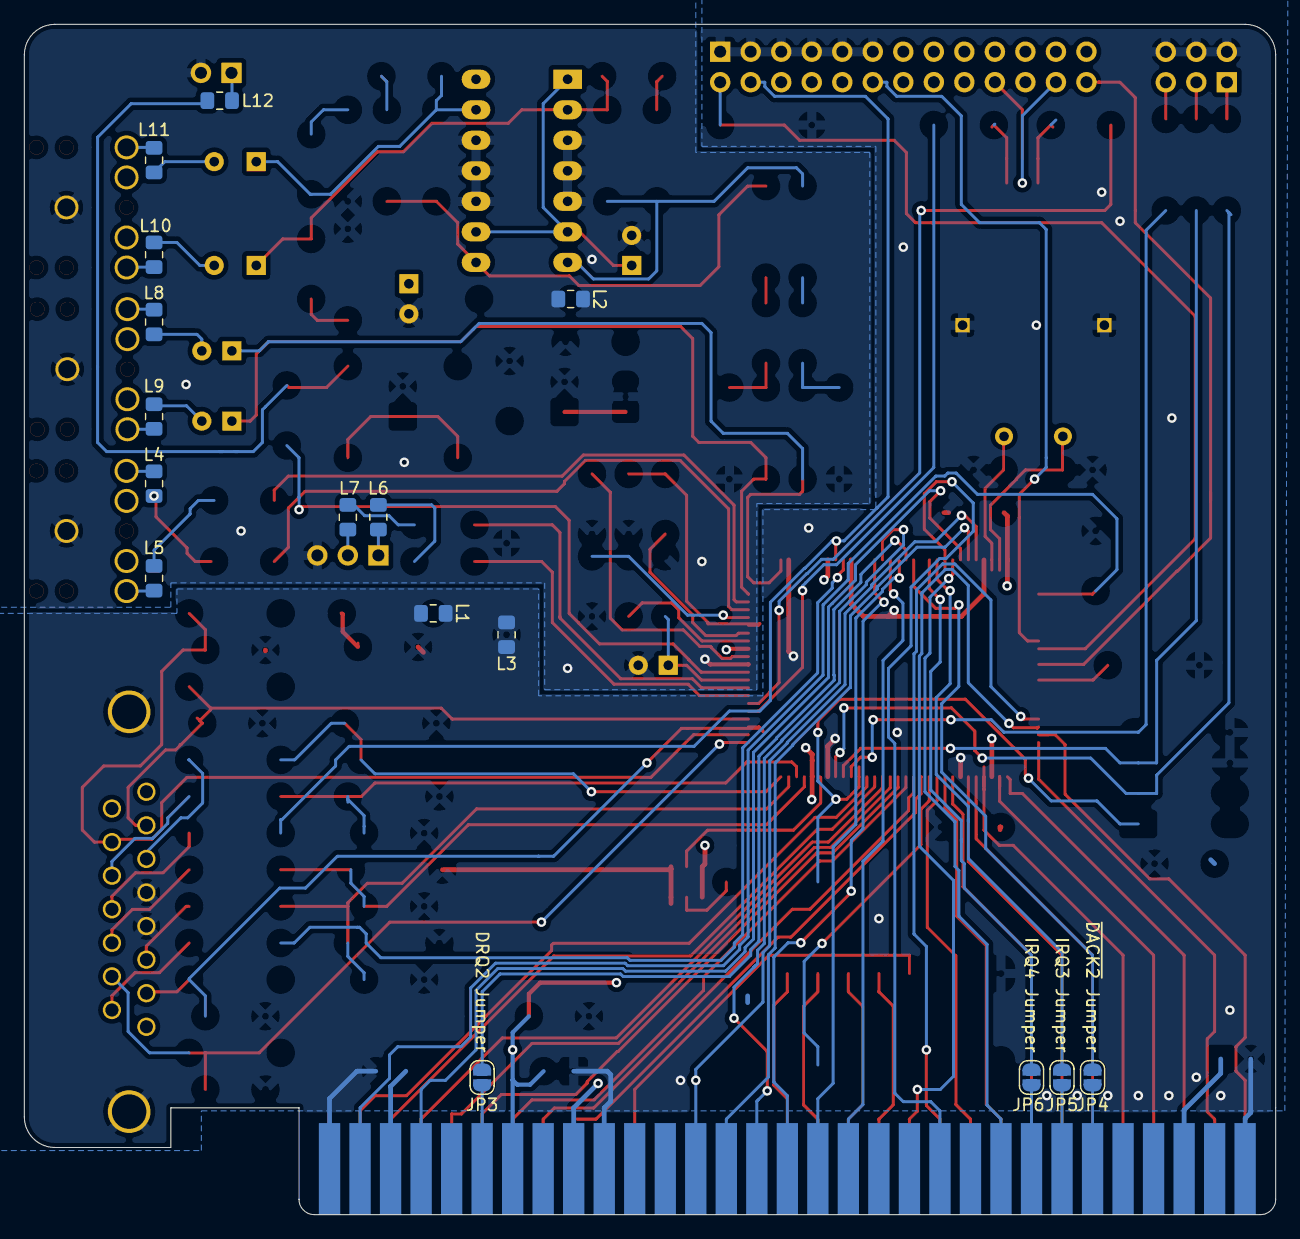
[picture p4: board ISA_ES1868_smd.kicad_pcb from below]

Board: 4 copper layers, 104.1 x 99.1 mm, 119 parts (16 on the bottom side), 134 nets.
